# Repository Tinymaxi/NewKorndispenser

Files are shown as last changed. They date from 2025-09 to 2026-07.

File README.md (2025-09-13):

# NewKorndispenser

This is the code for an apparatus that is able to dispense corn out of bags to a given amount.  
It runs on the Raspberry Pi Pico using the official Pico SDK and supports modules such as:

- HX711 load cell amplifier (for weighing)
- Rotary encoder with button (for menu navigation)
- LCD over I²C (for display)
- NeoPixel ring (for feedback/indicators)
- Buzzer/vibrator (for alerts)

The goal is to accurately measure and dispense a configurable quantity of corn.

## License
This project is licensed under the MIT License – see the [LICENSE](LICENSE) file for details.

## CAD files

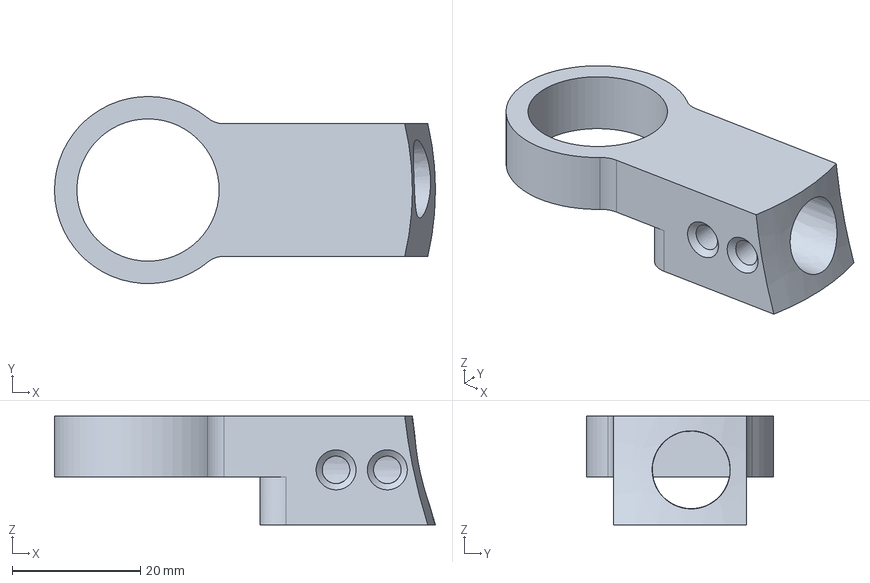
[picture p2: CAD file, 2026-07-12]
Korn Weighing Machine Quote/Insert v25.iges
59.5 x 29.2 x 17.0 mm

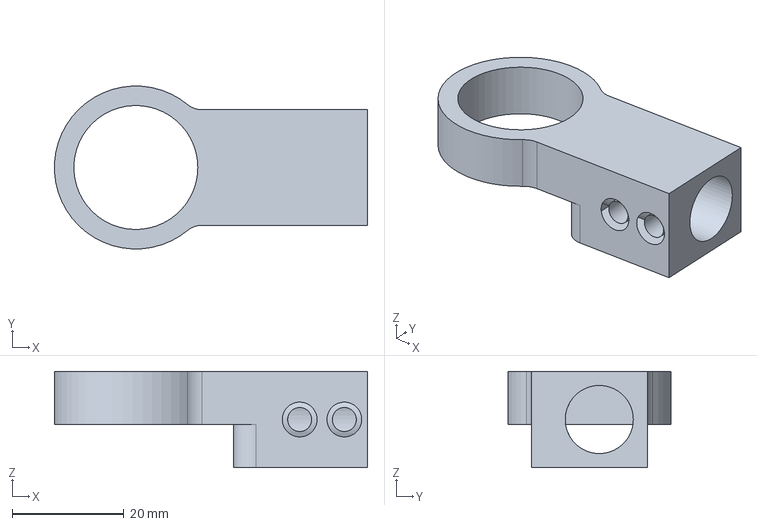
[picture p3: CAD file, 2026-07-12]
resources/Step and iges Files/Insert.step
56.1 x 29.2 x 17.2 mm

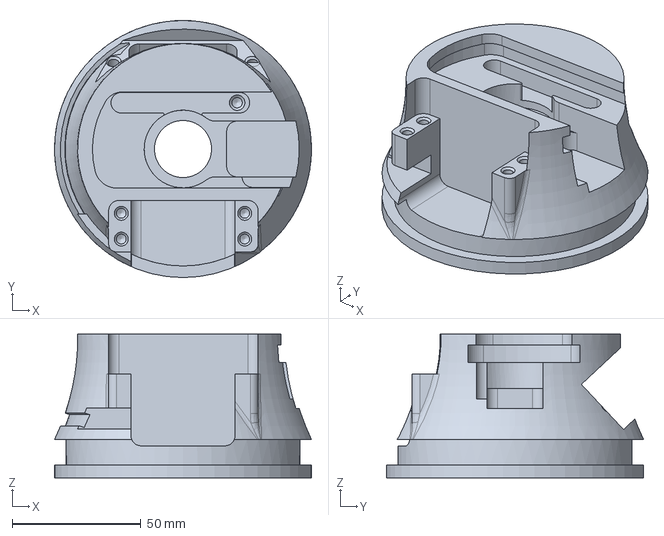
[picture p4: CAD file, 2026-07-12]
Korn Weighing Machine Quote/Funnel v55.step
100.0 x 100.0 x 56.0 mm

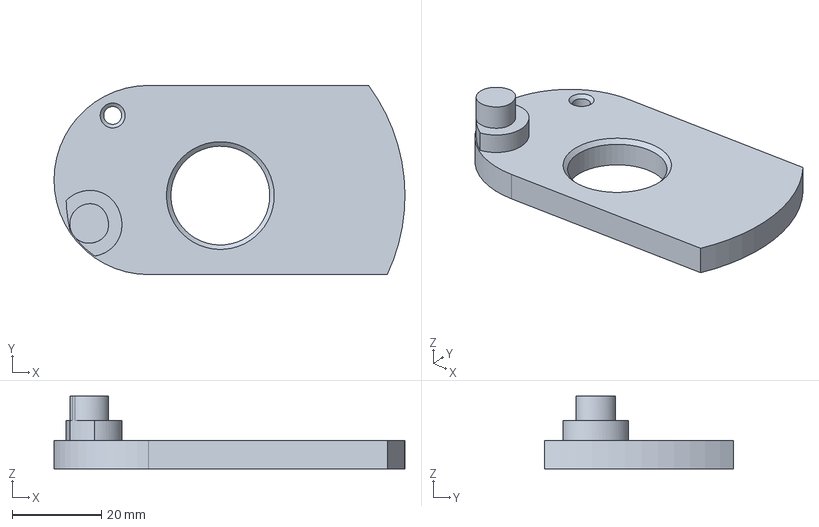
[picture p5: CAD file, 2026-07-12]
Korn Weighing Machine Quote/Slider v8.step
78.9 x 42.5 x 16.3 mm

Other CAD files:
Korn Weighing Machine Quote/Insert v26.step
resources/Step and iges Files/Insert v14.iges
resources/Step and iges Files/Funnel.step
resources/Step and iges Files/Slider v7.iges
resources/Step and iges Files/Slider.step
resources/Step and iges Files/Funnel v27.iges
Korn Weighing Machine Quote/Funnel v55.iges
Korn Weighing Machine Quote/Slider v8.iges

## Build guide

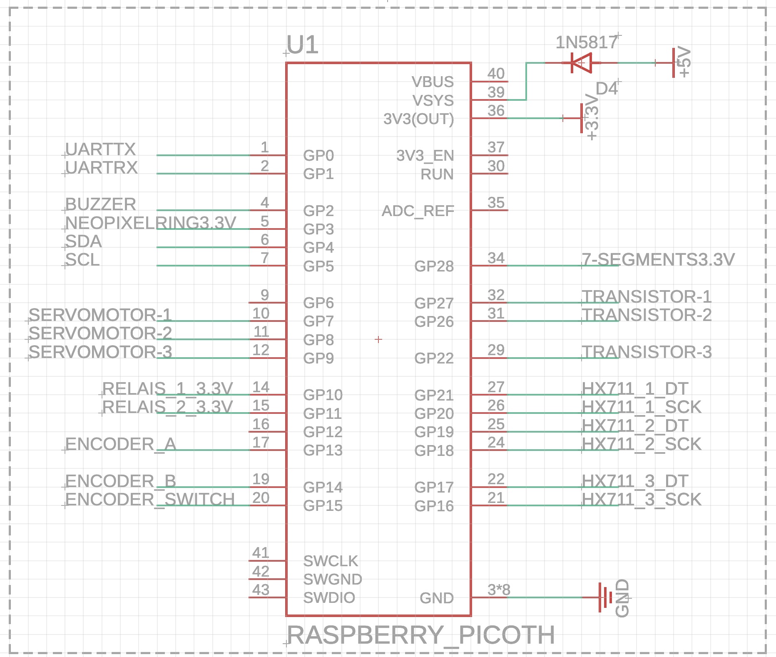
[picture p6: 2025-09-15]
resources/PicoWiring.jpg

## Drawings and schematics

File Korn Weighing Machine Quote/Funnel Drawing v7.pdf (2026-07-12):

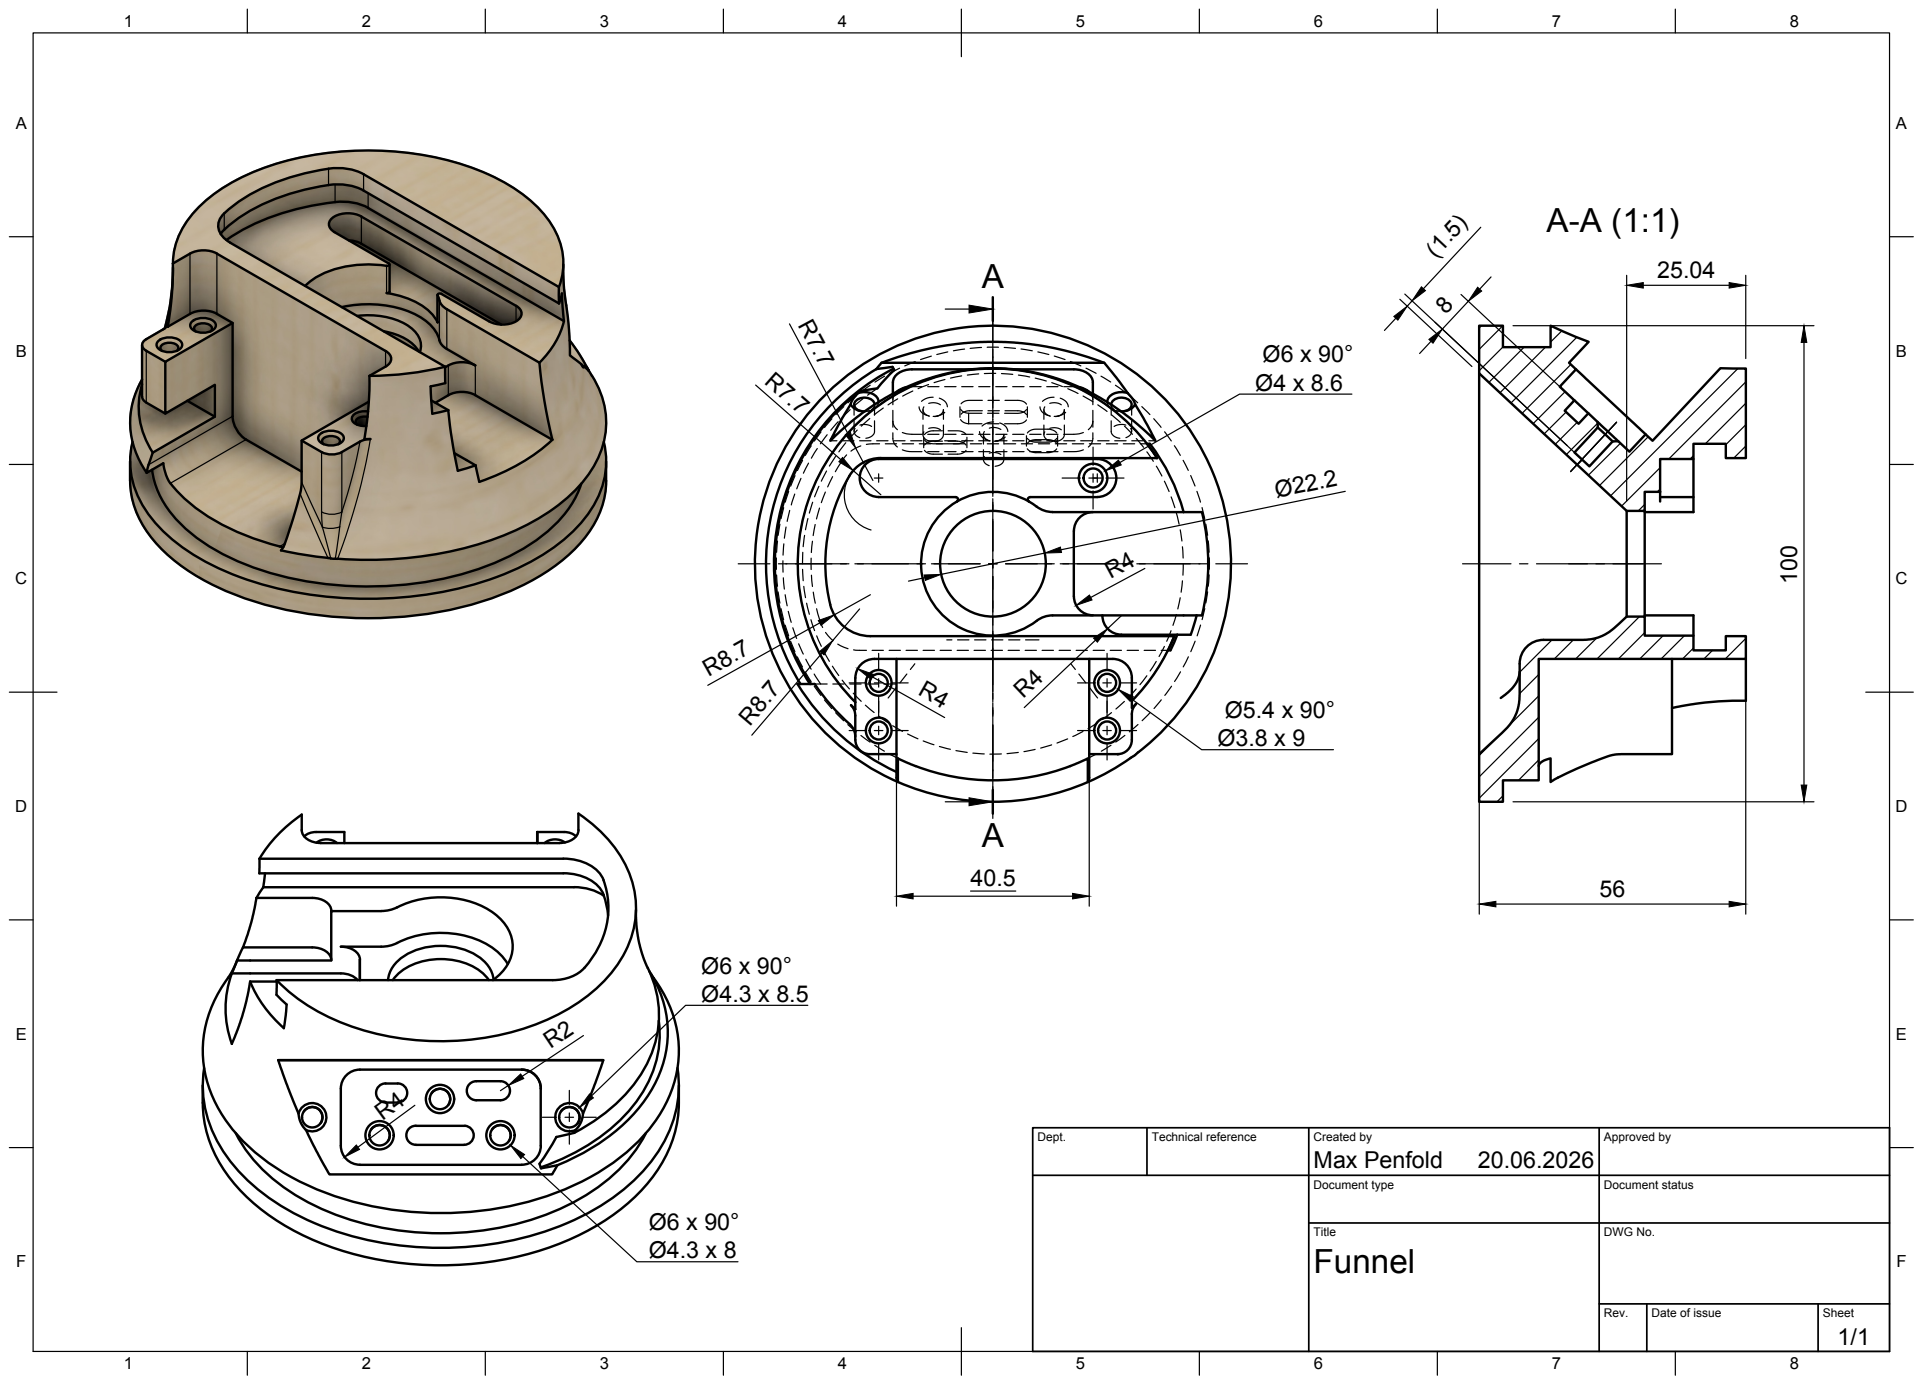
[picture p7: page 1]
Title; DWG No.; Rev.; Date of issue; Sheet

Dept. | Technical reference | Created by Max Penfold 20.06.2026 | Approved by

Document type | Document status

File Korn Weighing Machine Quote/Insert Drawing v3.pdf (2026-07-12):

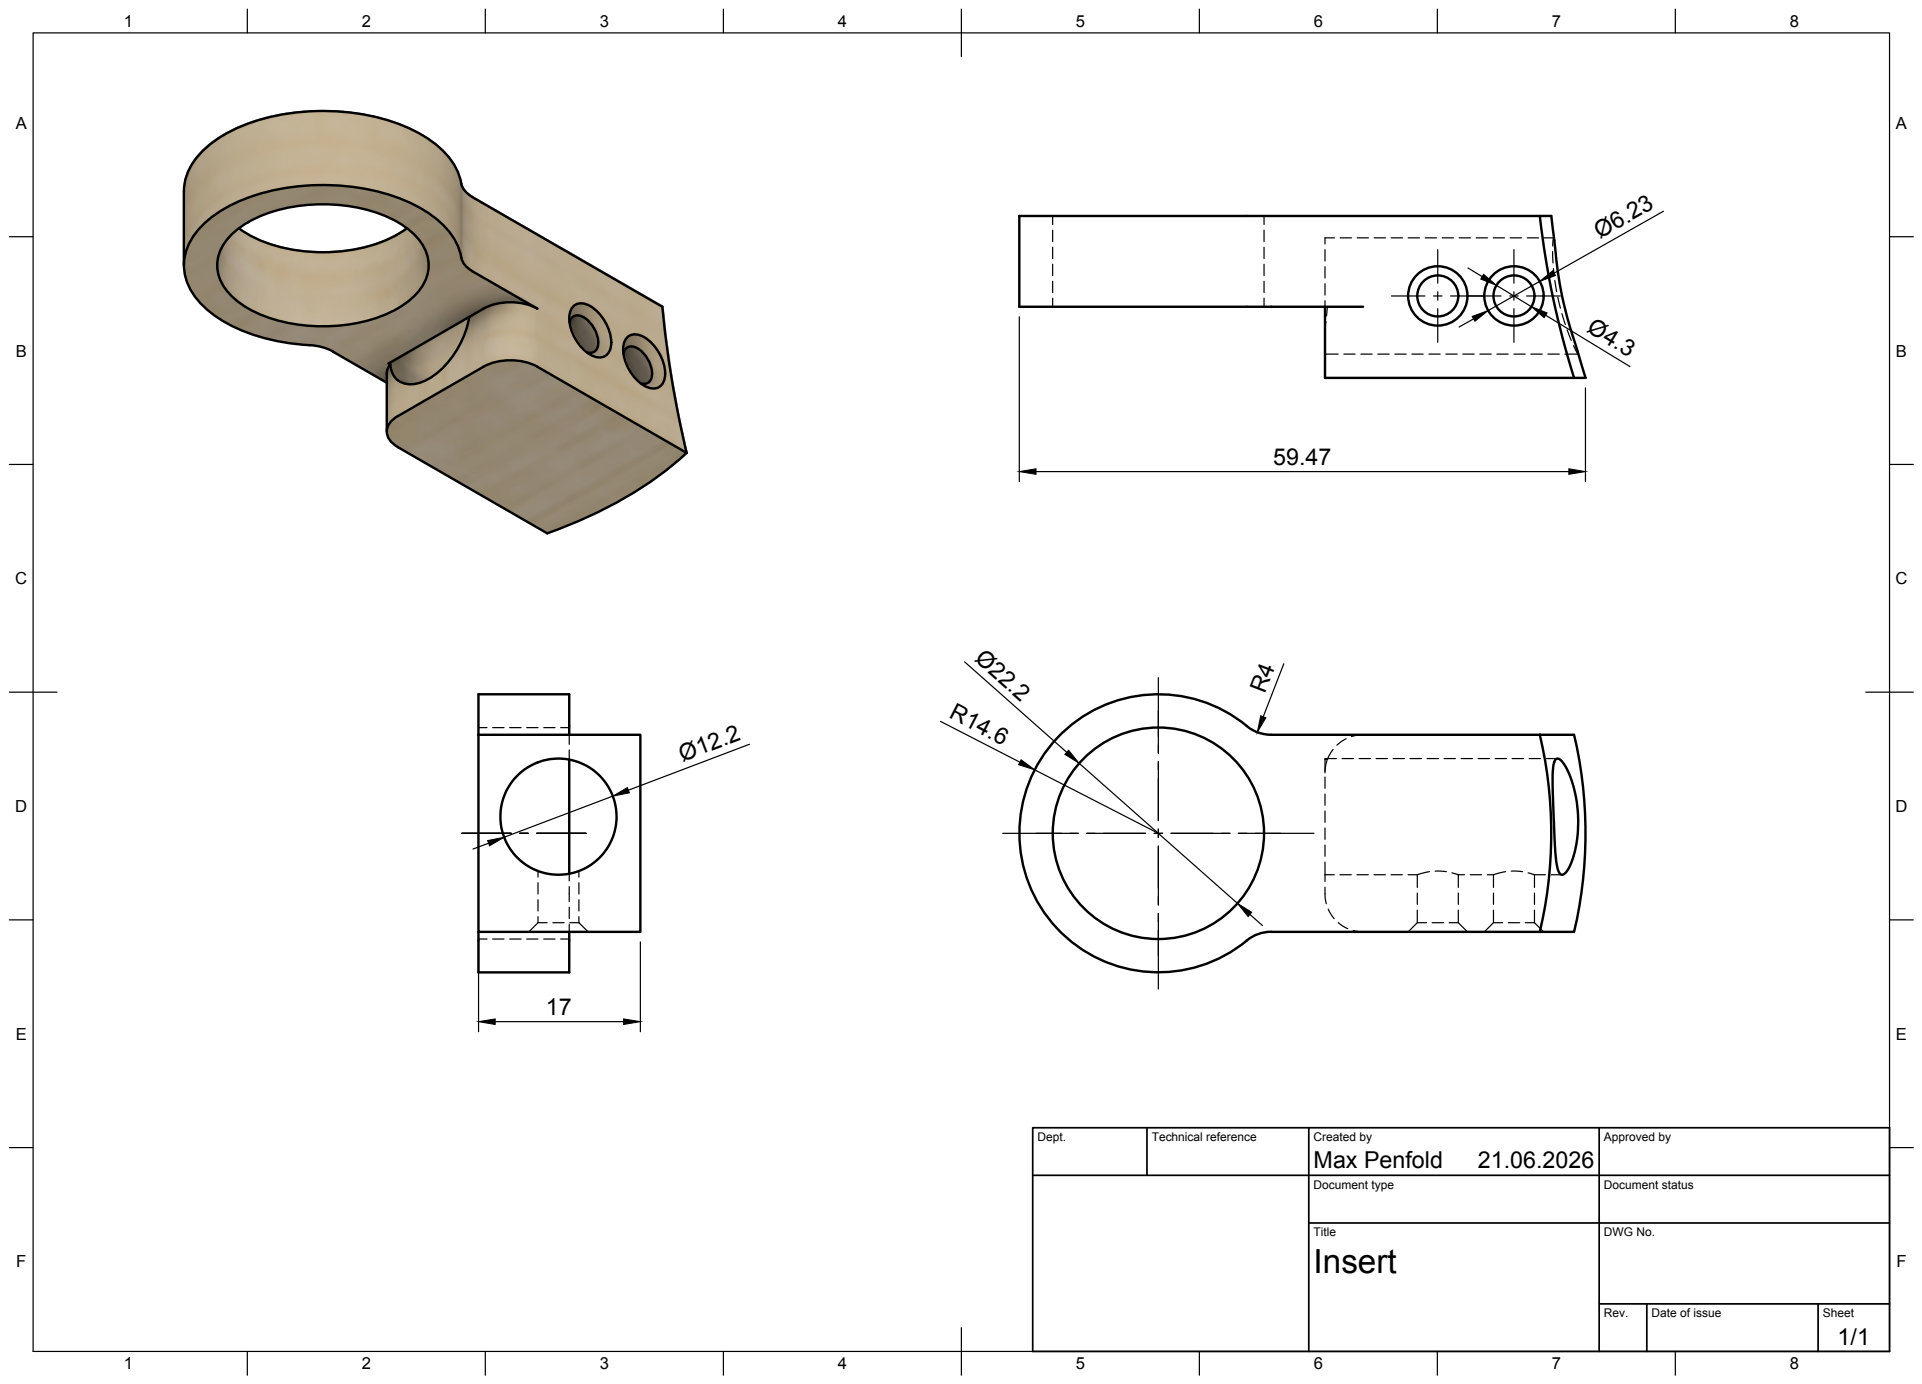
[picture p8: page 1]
Title; DWG No.; Rev.; Date of issue; Sheet

Dept. | Technical reference | Created by Max Penfold 21.06.2026 | Approved by

Document type | Document status

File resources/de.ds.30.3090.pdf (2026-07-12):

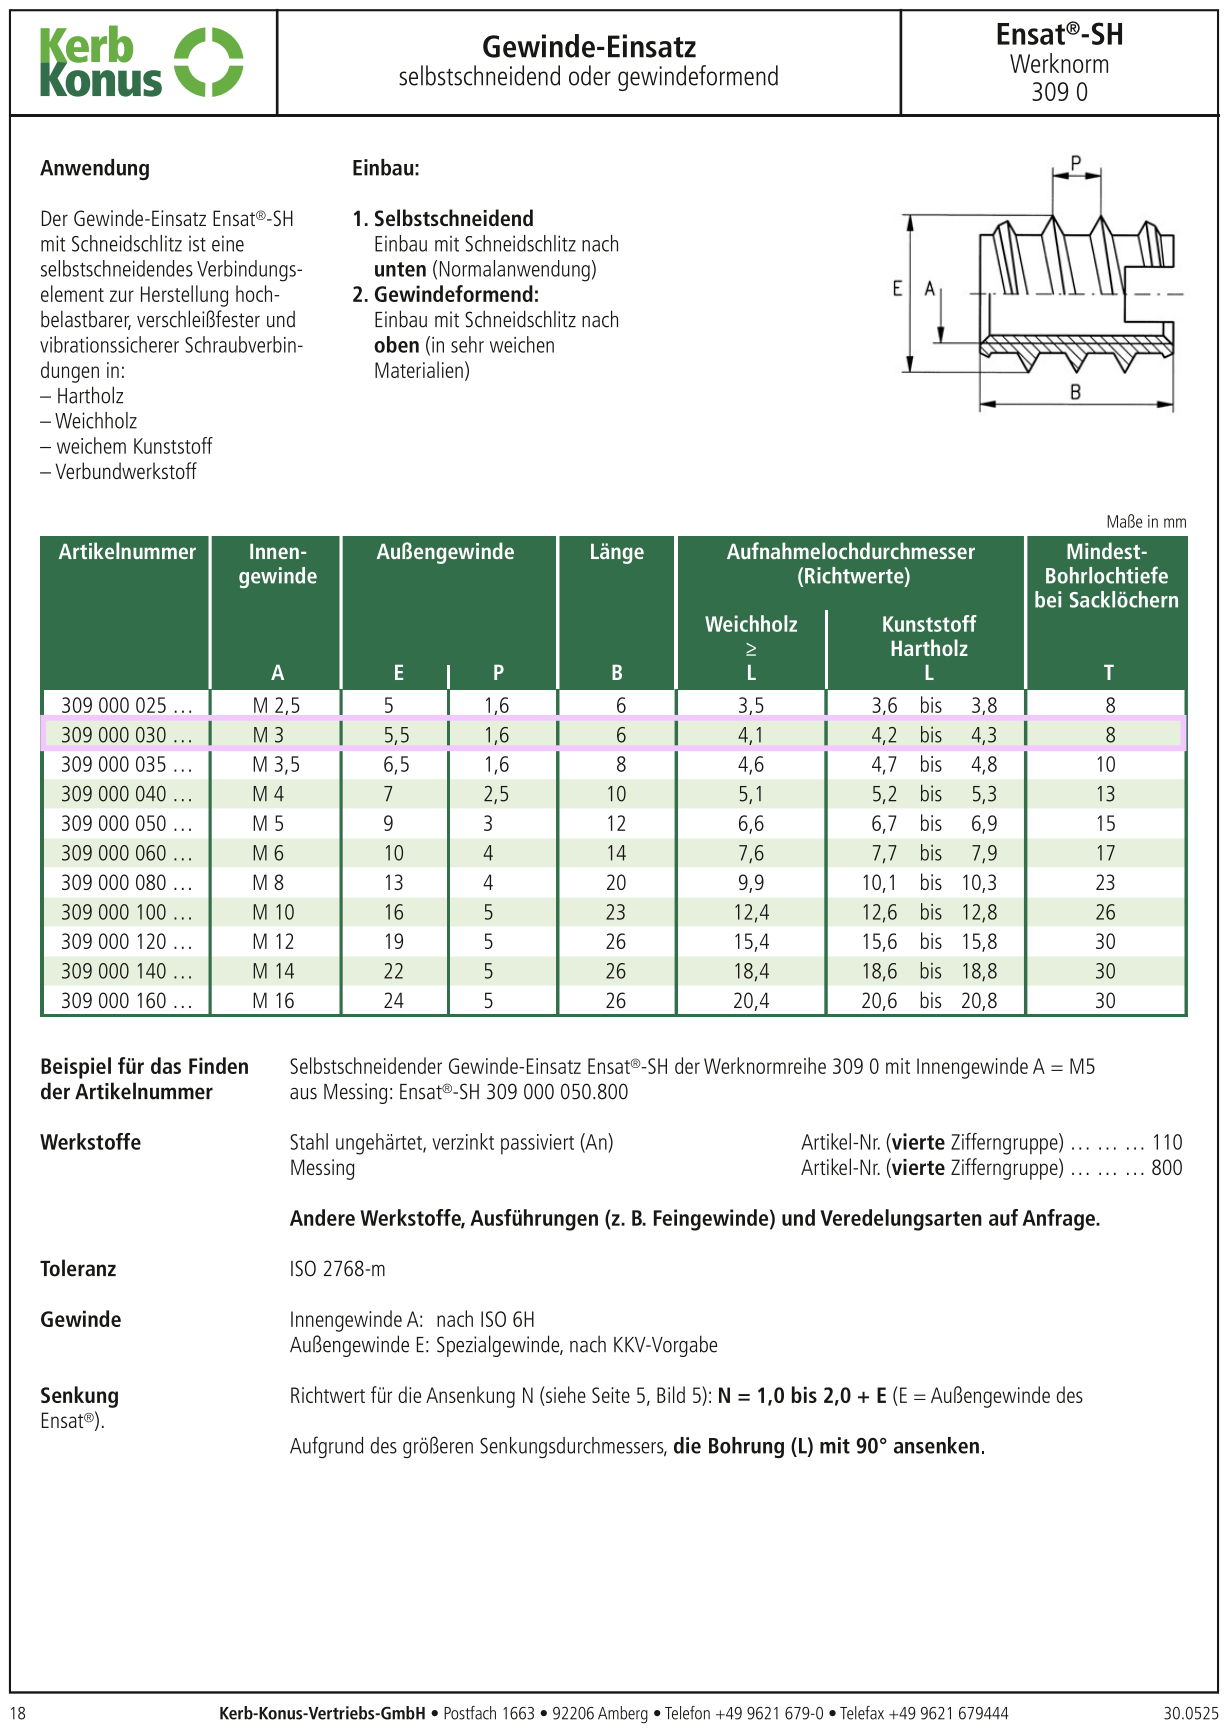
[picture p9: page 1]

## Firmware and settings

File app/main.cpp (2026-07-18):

#include "pico/stdlib.h"
#include "pico/cyw43_arch.h"
#include <cstdio>
#include <cstdlib>

#include "Buzzer.hpp"
#include "Rotary_Button.hpp"
#include "Lcd1602I2C.hpp"
#include "hx711.hpp"
#include "config_store.hpp"
#include "Ws2812.hpp"
#include "SevenSeg.hpp"
#include "Servo.hpp"
#include "Vibrator.hpp"
#include "SharedSlice.hpp"
#include "PID.hpp"
#include "screens.hpp"

#include "wifi_config.h"
#include "dispenser_state.h"
#include "web_server.h"
#include "dhserver.h"
#include "lwip/apps/mdns.h"

constexpr uint BUZZER_PIN = 2;
constexpr uint SEVENSEG_PIN = 28;
constexpr uint SEVENSEG_LEDS = 48;  // 6 digits x 8 segments

Rotary_Button enc;
Buzzer bz(BUZZER_PIN);
Lcd1602I2C lcd(i2c0, 0x27, 20, 4);

// Three load cell scales (from schematic)
hx711 scale1(20, 21);  // HX711_1: GP20=SCK, GP21=DT
hx711 scale2(18, 19);  // HX711_2: GP18=SCK, GP19=DT
hx711 scale3(16, 17);  // HX711_3: GP16=SCK, GP17=DT

// Array for easy access by index
hx711* scales[3] = {&scale1, &scale2, &scale3};

// Dispenser actuators - one per scale
Servo servo1(7);      // Scale 1 servo - GPIO 7
Servo servo2(8);      // Scale 2 servo - GPIO 8
Servo servo3(9);      // Scale 3 servo - GPIO 9
Servo* servos[3] = {&servo1, &servo2, &servo3};

Vibrator vib1(27);    // Scale 1 vibrator - GPIO 27
Vibrator vib2(26);    // Scale 2 vibrator - GPIO 26
Vibrator vib3(22);    // Scale 3 vibrator - GPIO 22
Vibrator* vibrators[3] = {&vib1, &vib2, &vib3};

// servo1 (GP7) and vib3 (GP22) both live on PWM slice 3, which can only hold one
// frequency. This coordinator runs the slice at the servo's 333 Hz whenever servo1
// is active and hands it back to the vibrator's 20 kHz otherwise (see main()).
SharedSlice slice3_pwm;

// Pointers - initialized in main() to avoid PIO conflict with encoder
Ws2812* sevenSegStrip = nullptr;
SevenSeg* sevenSeg = nullptr;

ScaleConfig sc;

// Shared state for web interface
DispenserState g_state;

// True once cyw43_arch_init() has succeeded - lwIP callbacks may then run in the
// background IRQ context, and shared state must be guarded with the lwIP lock.
static bool net_stack_up = false;
static inline void net_lock()   { if (net_stack_up) cyw43_arch_lwip_begin(); }
static inline void net_unlock() { if (net_stack_up) cyw43_arch_lwip_end(); }

// PID tuning parameters (mutable for web-based tuning)
static double Kp = 1.5, Ki = 0.08, Kd = 0.8;
static PID* dispense_pid = nullptr;
static bool pid_save_pending = false;  // Deferred flash save (never write mid-dispense)

static void save_pid_gains() {
    PidConfig pc;
    pc.kp = (float)Kp;
    pc.ki = (float)Ki;
    pc.kd = (float)Kd;
    save_pid_config(pc);  // stalls IRQs ~100 ms - only call while not dispensing
}

// Scale content names ("Wheat", "Spelt", ...) - mirrored in g_state.names for
// the web UI and persisted to flash. Deferred like the PID save: flash writes
// stall IRQs ~100 ms and must never land mid-dispense.
static bool name_save_pending = false;

static void save_scale_names() {
    NameConfig nc;
    for (int i = 0; i < 3; i++) {
        std::snprintf(nc.names[i], SCALE_NAME_LEN, "%s", g_state.names[i]);
    }
    save_name_config(nc);
}

// Per-servo zero (flow-start) angles - mirrored in g_state.servo_zero and
// persisted to flash. Same deferred-save rule as the PID gains and names.
static bool servo_save_pending = false;

static void save_servo_zeros() {
    ServoConfig svc;
    for (int i = 0; i < 3; i++) {
        svc.open_deg[i] = g_state.servo_zero[i];
    }
    save_servo_config(svc);
}

// --- Access-point fallback ---------------------------------------------------
// When the router is unreachable, the Pico broadcasts its own network so a phone
// can join it directly and use the web app at http://192.168.4.1.
static dhcp_entry_t dhcp_entries[] = {
    { {0}, {192, 168, 4, 16}, {255, 255, 255, 0}, 24 * 3600 },
    { {0}, {192, 168, 4, 17}, {255, 255, 255, 0}, 24 * 3600 },
    { {0}, {192, 168, 4, 18}, {255, 255, 255, 0}, 24 * 3600 },
    { {0}, {192, 168, 4, 19}, {255, 255, 255, 0}, 24 * 3600 },
};

static dhcp_config_t dhcp_cfg = {
    {192, 168, 4, 1},                // server address
    67,                              // port
    {192, 168, 4, 1},                // dns (points at us; we run no DNS - harmless)
    "korn",                          // domain suffix
    sizeof(dhcp_entries) / sizeof(dhcp_entries[0]),
    dhcp_entries
};

// Announce this device as http://korn.local via mDNS/Bonjour so a printed QR
// code works regardless of the DHCP-assigned IP. netif_default is the active
// interface in both STA and AP mode. Call after the IP is up.
static void start_mdns() {
    cyw43_arch_lwip_begin();
    mdns_resp_init();
    mdns_resp_add_netif(netif_default, "korn");
    mdns_resp_add_service(netif_default, "korn", "_http", DNSSD_PROTO_TCP, 80, NULL, NULL);
    mdns_resp_announce(netif_default);
    cyw43_arch_lwip_end();
    printf("[mdns] korn.local up\n");
}

static bool start_ap_mode() {
    cyw43_arch_disable_sta_mode();
    // The AP netif is auto-configured to 192.168.4.1/24 by the cyw43 driver
    cyw43_arch_enable_ap_mode(WIFI_AP_SSID, WIFI_AP_PASSWORD, CYW43_AUTH_WPA2_AES_PSK);

    cyw43_arch_lwip_begin();
    err_t e = dhserv_init(&dhcp_cfg);
    cyw43_arch_lwip_end();
    if (e != ERR_OK) {
        printf("[wifi] AP dhcp server failed: %d\n", (int)e);
        return false;
    }
    printf("[wifi] AP mode: %s at 192.168.4.1\n", WIFI_AP_SSID);
    return true;
}

int main()
{
    stdio_init_all();

    // Load persisted PID gains (if ever saved) before the controller is created
    {
        PidConfig pc;
        if (load_pid_config(pc)) {
            Kp = pc.kp;
            Ki = pc.ki;
            Kd = pc.kd;
        }
    }

    // Load persisted scale content names
    {
        NameConfig nc;
        if (load_name_config(nc)) {
            for (int i = 0; i < 3; i++) {
                std::snprintf(g_state.names[i], sizeof(g_state.names[i]), "%s", nc.names[i]);
            }
        }
    }

    // Load persisted servo zero angles (before the startup close below, which
    // parks each servo relative to its zero)
    {
        ServoConfig svc;
        if (load_servo_config(svc)) {
            for (int i = 0; i < 3; i++) {
                g_state.servo_zero[i] = svc.open_deg[i];
            }
        }
    }

    // Link servo1 + vib3 on shared PWM slice 3 before any servo/vibrator output, so
    // the slice frequency is arbitrated from the very first startup close below.
    servo1.attachShared(&slice3_pwm);
    vib3.attachShared(&slice3_pwm);

    // Close all servos at startup, then release (no holding torque)
    for (int i = 0; i < 3; i++) {
        servos[i]->writeDegrees(servo_close(g_state, i));
    }
    sleep_ms(500);  // Give servos time to reach position
    for (int i = 0; i < 3; i++) {
        servos[i]->off();  // Release - no holding torque
    }

    // Give USB serial a moment to connect (non-blocking)
    sleep_ms(1000);
    printf("Ready.\r\r\n");

    lcd.init(PICO_DEFAULT_I2C_SDA_PIN, PICO_DEFAULT_I2C_SCL_PIN, 100000);

    // --- Network mode chooser --------------------------------------------
    // Pick Home WiFi (STA, still falls back to the hotspot if it fails) or
    // Hotspot (AP) with the encoder. Auto-continues with the remembered
    // choice after 5 s, so unattended power cycles never wait on a person.
    uint8_t net_mode = 0;  // 0 = Home WiFi, 1 = Hotspot
    {
        NetConfig ncfg;
        if (load_net_config(ncfg)) net_mode = ncfg.mode;

        lcd.clear();
        lcd.setCursor(0, 0);
        lcd.print("Network?");

        int  sel = net_mode;
        int  last_sel = -1, last_secs = -1;
        int  last_pos = enc.getPosition();
        absolute_time_t deadline = make_timeout_time_ms(5000);

        // Glitch protection: right after boot the button line can show a
        // spurious edge and the encoder's stable-position filter settles with
        // one jump - either instantly "confirmed" the menu. So: ignore
        // position changes during a warm-up, arm the button only after it has
        // read released continuously for 150 ms, and require two consecutive
        // pressed reads (~60 ms) to confirm.
        absolute_time_t warmup = make_timeout_time_ms(300);
        absolute_time_t released_since = get_absolute_time();
        bool armed = false;
        int  press_reads = 0;

        while (!time_reached(deadline)) {
            int pos = enc.getPosition();
            if (pos != last_pos) {
                if (time_reached(warmup)) {
                    sel = (pos > last_pos) ? 1 : 0;  // two entries: turn down/up
                    deadline = make_timeout_time_ms(5000);  // interaction resets timer
                }
                last_pos = pos;
            }

            if (enc.isPressed()) {
                if (armed && ++press_reads >= 2) {
                    printf("[net] chooser: confirmed by press\n");
                    break;
                }
                released_since = get_absolute_time();  // not armed: keep waiting
            } else {
                press_reads = 0;
                if (!armed &&
                    absolute_time_diff_us(released_since, get_absolute_time()) >= 150000) {
                    armed = true;
                }
            }

            if (sel != last_sel) {
                lcd.setCursor(1, 0);
                lcd.print(sel == 0 ? "> Home WiFi    " : "  Home WiFi    ");
                lcd.setCursor(2, 0);
                lcd.print(sel == 1 ? "> Hotspot      " : "  Hotspot      ");
                last_sel = sel;
            }
            int secs = (int)((absolute_time_diff_us(get_absolute_time(), deadline)
                              + 999999) / 1000000);
            if (secs != last_secs) {
                char cdl[21];
                std::snprintf(cdl, sizeof(cdl), "Auto in %ds  Press=OK", secs);
                lcd.setCursor(3, 0);
                lcd.print(cdl);
                last_secs = secs;
            }
            sleep_ms(30);
        }

        printf("[net] chooser result: %s\n", sel == 1 ? "Hotspot" : "Home WiFi");
        if ((uint8_t)sel != net_mode) {
            net_mode = (uint8_t)sel;
            ncfg.mode = net_mode;
            save_net_config(ncfg);  // remembered as next boot's default
        }
    }

    // --- WiFi initialization ---
    if (cyw43_arch_init()) {
        printf("[wifi] init failed\n");
        lcd.clear();
        lcd.setCursor(0, 0);
        lcd.print("WiFi init failed!");
        sleep_ms(2000);
    } else {
        net_stack_up = true;

        // Hotspot chosen at the boot menu skips the STA attempts entirely
        bool force_ap = (net_mode == 1);

        int wifi_err = -1;
        if (!force_ap) {
            cyw43_arch_enable_sta_mode();
            lcd.clear();
            lcd.setCursor(0, 0);
            lcd.print("Connecting WiFi...");
            lcd.setCursor(1, 0);
            lcd.print(WIFI_SSID);
            printf("[wifi] connecting to %s...\n", WIFI_SSID);

            for (int attempt = 1; attempt <= 3 && wifi_err != 0; attempt++) {
                printf("[wifi] attempt %d/3...\n", attempt);
                lcd.setCursor(2, 0);
                char att_line[21];
                std::snprintf(att_line, sizeof(att_line), "Attempt %d/3...      ", attempt);
                lcd.print(att_line);

                wifi_err = cyw43_arch_wifi_connect_timeout_ms(
                    WIFI_SSID, WIFI_PASSWORD, CYW43_AUTH_WPA2_AES_PSK, 20000);

                if (wifi_err) {
                    printf("[wifi] attempt %d failed: %d\n", attempt, wifi_err);
                }
            }
        }

        if (wifi_err == 0) {
            const ip4_addr_t* ip = netif_ip4_addr(netif_default);
            char ip_str[20];
            snprintf(ip_str, sizeof(ip_str), "%s", ip4addr_ntoa(ip));
            printf("[wifi] connected: %s\n", ip_str);

            lcd.setCursor(2, 0);
            char ip_line[21];
            std::snprintf(ip_line, sizeof(ip_line), "IP: %s", ip_str);
            lcd.print(ip_line);
            lcd.setCursor(3, 0);
            lcd.print("http://korn.local");

            // Start web server + mDNS (korn.local)
            web_server_init(&g_state, WEB_SERVER_PORT);
            start_mdns();
            sleep_ms(2000);
        } else {
            // STA failed (or AP forced) - broadcast our own network instead
            if (!force_ap) printf("[wifi] all attempts failed: %d\n", wifi_err);
            lcd.clear();
            lcd.setCursor(0, 0);
            lcd.print(force_ap ? "Hotspot mode" : "WiFi failed - AP up");

            if (start_ap_mode()) {
                g_state.ap_mode = true;
                lcd.setCursor(1, 0);
                lcd.print("AP: " WIFI_AP_SSID);
                lcd.setCursor(2, 0);
                lcd.print("Pass: " WIFI_AP_PASSWORD);
                lcd.setCursor(3, 0);
                lcd.print("http://192.168.4.1");

                web_server_init(&g_state, WEB_SERVER_PORT);
                start_mdns();   // korn.local works in AP mode too
                sleep_ms(4000);
            } else {
                lcd.setCursor(3, 0);
                lcd.print("Continuing offline..");
                sleep_ms(3000);
            }
        }
    }

    bz.playMacStartup(); // Mac-like startup chime

    // Initialize 7-segment display after encoder to avoid PIO conflict.
    // Full brightness for the boot animation; dimmed to ~1/3 after it.
    sevenSegStrip = new Ws2812(SEVENSEG_PIN, SEVENSEG_LEDS);
    sevenSeg = new SevenSeg(*sevenSegStrip, LAYOUT_6DIGITS);

    // --- 7-segment startup animation: random segments sweep left to right ---
    {
        const uint8_t ORANGE_R = 255, ORANGE_G = 80, ORANGE_B = 0;
        const int SWEEP_DELAY_MS = 40;  // Speed of sweep
        const int HOLD_MS = 3300;       // Hold at end before clearing

        // Seed random with time
        srand(to_ms_since_boot(get_absolute_time()));

        // Sweep from left to right, lighting random segments
        for (int digit = 0; digit < 6; digit++) {
            // Generate random segment mask (at least 2 segments lit)
            uint8_t mask = 0;
            int lit_count = 0;
            while (lit_count < 2) {
                mask = rand() % 128;  // 7 bits for 7 segments
                lit_count = 0;
                for (int b = 0; b < 7; b++) {
                    if (mask & (1 << b)) lit_count++;
                }
            }

            sevenSeg->setDigitMask(digit, mask, ORANGE_R, ORANGE_G, ORANGE_B);
            sevenSeg->show();
            sleep_ms(SWEEP_DELAY_MS);
        }

        // Brief hold showing all random segments
        sleep_ms(HOLD_MS);

        // Quick fade out sweep right to left
        for (int digit = 5; digit >= 0; digit--) {
            sevenSeg->setDigitMask(digit, 0, 0, 0, 0);
            sevenSeg->show();
            sleep_ms(SWEEP_DELAY_MS / 2);
        }
    }

    // Normal operation runs dimmed (~1/3) - full white was blinding
    sevenSegStrip->setBrightness(85);

    bool isConfigured = false;

    if (load_scale_config(sc))
    {
        // Apply config to all 3 scales
        apply_scale_config(scale1, sc.entries[0]);
        apply_scale_config(scale2, sc.entries[1]);
        apply_scale_config(scale3, sc.entries[2]);

        // Check if at least one scale is configured
        int configured_count = 0;
        for (int i = 0; i < 3; i++) {
            if (scales[i]->get_offset() != 0 || scales[i]->get_scale() != 1.0f) {
                configured_count++;
            }
        }

        lcd.clear();
        if (configured_count == 0)
        {
            lcd.setCursor(0, 0);
            lcd.print("     No valid");
            lcd.setCursor(1, 0);
            lcd.print("  config in flash!   ");
            lcd.setCursor(2, 0);
            lcd.print("Please calibrate");
            sleep_ms(2500);
        }
        else
        {
            isConfigured = true;
            lcd.setCursor(0, 0);
            lcd.print("   Loaded config   ");
            char line[21];
            std::snprintf(line, sizeof(line), "%d of 3 scales ready", configured_count);
            lcd.setCursor(1, 0);
            lcd.print(line);
            sleep_ms(2500);
        }
    }
    else
    {
        lcd.clear();
        lcd.setCursor(0, 0);
        lcd.print("     No valid");
        lcd.setCursor(1, 0);
        lcd.print("  config in flash   ");
        sleep_ms(2500);
    }

    // UI context shared by the screen classes (app/screens.cpp) and the web
    // command dispatcher below
    UiContext ctx{
        lcd, enc, bz, scales, servos, vibrators, sevenSeg, sc, g_state,
        Kp, Ki, Kd, dispense_pid, &net_lock, &net_unlock
    };
    ctx.names = g_state.names;

    ScreenManager mgr;
    mgr.init(ctx, isConfigured ? ScreenId::Menu : ScreenId::SelectScale);

    // Timestamp for periodic background weight reads
    absolute_time_t last_bg_weight_time = get_absolute_time();
    int bg_weight_cycle = 0;  // cycles through non-selected scales

    while (true)
    {
        // --- Web state sync: update g_state from local variables ---
        // Scale reads happen OUTSIDE the lwIP lock (they bit-bang the HX711);
        // only the g_state assignments are guarded so /api/status snapshots
        // taken in the lwIP IRQ context can't tear across fields.
        bool have_weights = false;
        float w_sel = 0.0f, w_other = 0.0f;
        float gr_sel = 0.0f, gr_other = 0.0f;
        int other = (ctx.selected_scale + 1 + bg_weight_cycle) % 3;
        if (absolute_time_diff_us(last_bg_weight_time, get_absolute_time()) > 250000) {
            w_sel = scales[ctx.selected_scale]->read_weight();
            gr_sel = scales[ctx.selected_scale]->last_gross();   // same raw sample
            if (other != ctx.selected_scale) {
                w_other = scales[other]->read_weight();
                gr_other = scales[other]->last_gross();
            }
            have_weights = true;
            bg_weight_cycle = (bg_weight_cycle + 1) % 2;
            last_bg_weight_time = get_absolute_time();
        }

        net_lock();
        g_state.selected_scale = ctx.selected_scale;
        g_state.target_grams = ctx.target_grams;
        if (have_weights) {
            g_state.weights[ctx.selected_scale] = w_sel;
            g_state.gross[ctx.selected_scale] = gr_sel;
            if (other != ctx.selected_scale) {
                g_state.weights[other] = w_other;
                g_state.gross[other] = gr_other;
            }
        }
        g_state.pid_kp = (float)Kp;
        g_state.pid_ki = (float)Ki;
        g_state.pid_kd = (float)Kd;
        for (int i = 0; i < 3; i++) {
            g_state.scale_calibrated[i] =
                (scales[i]->get_offset() != 0 || scales[i]->get_scale() != 1.0f);
        }
        net_unlock();

        // --- Web command dispatch ---
        // Drain ALL queued commands in order (the queue means nothing gets lost
        // while a blocking tare/calibrate stalls the loop). Pop under the lwIP
        // lock, dispatch from the copy.
        while (true) {
            WebCmd c;
            net_lock();
            bool have = (g_state.cmd_tail != g_state.cmd_head);
            if (have) {
                c = g_state.cmd_queue[g_state.cmd_tail];
                g_state.cmd_tail = (uint8_t)((g_state.cmd_tail + 1) % WEBCMD_QUEUE_LEN);
            }
            net_unlock();
            if (!have) break;

            ctx.web_active = true;  // Web is in control, disable hardware input

            switch (c.cmd) {
            case WebCommand::Tare:
                // tare blocks ~1.6 s - never stall the PID with the gate open
                if (g_state.dispensing) break;
                scales[ctx.selected_scale]->tare();
                bz.playMarioCoin();
                // Publish the tared reading immediately so the next status poll
                // shows ~0 instead of the stale pre-tare weight
                {
                    float wnew = scales[ctx.selected_scale]->read_weight();
                    net_lock();
                    g_state.weights[ctx.selected_scale] = wnew;
                    g_state.gross[ctx.selected_scale] = scales[ctx.selected_scale]->last_gross();
                    net_unlock();
                }
                break;

            case WebCommand::SetTarget:
                ctx.target_grams = c.i0;
                if (ctx.target_grams < 1) ctx.target_grams = 1;
                if (ctx.target_grams > 9999) ctx.target_grams = 9999;
                break;

            case WebCommand::SelectScale:
                if (c.i0 >= 0 && c.i0 <= 2) {
                    ctx.selected_scale = c.i0;
                }
                break;

            case WebCommand::StartDispense:
                // Jump to the dispense screen and flag it to auto-start
                if (!g_state.dispensing) {
                    ctx.web_start_dispense = true;
                    g_state.dispense_done = false;
                    mgr.goTo(ctx, ScreenId::Dispense);
                }
                break;

            case WebCommand::StopDispense:
                // Route through the Dispense screen's Running state so the state
                // machine, telemetry and web state all stop consistently. (Closing
                // the servo here alone is not enough - Running would re-open it.)
                if (g_state.dispensing) {
                    ctx.web_stop_dispense = true;
                }
                break;
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

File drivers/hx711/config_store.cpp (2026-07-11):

#include "config_store.hpp"

#include <cstddef>
#include <cstring>

#include "pico/stdlib.h"
#include "hardware/flash.h"
#include "hardware/sync.h" 

#ifndef CFG_SECTOR_SIZE
#define CFG_SECTOR_SIZE   FLASH_SECTOR_SIZE   // 4096
#endif
#ifndef CFG_PAGE_SIZE
#define CFG_PAGE_SIZE     FLASH_PAGE_SIZE     // 256
#endif

static constexpr uint32_t CFG_OFFSET   = (PICO_FLASH_SIZE_BYTES - CFG_SECTOR_SIZE);
static constexpr uint32_t CFG_XIP_ADDR = (XIP_BASE + CFG_OFFSET);

// CRC32 (poly 0xEDB88320)
static uint32_t crc32_calc(const void* data, size_t len) {
    const uint8_t* p = static_cast<const uint8_t*>(data);
    uint32_t c = 0xFFFFFFFFu;
    for (size_t i = 0; i < len; ++i) {
        c ^= p[i];
        for (int b = 0; b < 8; ++b) {
            c = (c >> 1) ^ (0xEDB88320u & (-(int)(c & 1)));
        }
    }
    return ~c;
}

bool load_scale_config(ScaleConfig& cfg) {
    ScaleConfig tmp{};
    std::memcpy(&tmp, reinterpret_cast<const void*>(CFG_XIP_ADDR), sizeof(tmp));

    if (tmp.magic != 0x48583133) return false;

    uint32_t expected = crc32_calc(&tmp, offsetof(ScaleConfig, crc32));
    if (expected != tmp.crc32) return false;

    cfg = tmp;
    return true;
}

bool save_scale_config(const ScaleConfig& cfg_in) {
    alignas(FLASH_PAGE_SIZE) static uint8_t sector_buf[CFG_SECTOR_SIZE];
    std::memset(sector_buf, 0xFF, sizeof(sector_buf));

    ScaleConfig tmp = cfg_in;
    tmp.crc32 = crc32_calc(&tmp, offsetof(ScaleConfig, crc32));
    std::memcpy(sector_buf, &tmp, sizeof(tmp));

    uint32_t irq_state = save_and_disable_interrupts();
    flash_range_erase(CFG_OFFSET, CFG_SECTOR_SIZE);
    flash_range_program(CFG_OFFSET, sector_buf, CFG_SECTOR_SIZE);
    restore_interrupts(irq_state);

    ScaleConfig check{};
    std::memcpy(&check, reinterpret_cast<const void*>(CFG_XIP_ADDR), sizeof(check));
    return (check.magic == tmp.magic) && (check.crc32 == tmp.crc32);
}
// ---- PID gain persistence (second-to-last sector; calibration untouched) ----

static constexpr uint32_t PID_CFG_OFFSET   = (PICO_FLASH_SIZE_BYTES - 2 * CFG_SECTOR_SIZE);
static constexpr uint32_t PID_CFG_XIP_ADDR = (XIP_BASE + PID_CFG_OFFSET);

bool load_pid_config(PidConfig& cfg) {
    PidConfig tmp{};
    std::memcpy(&tmp, reinterpret_cast<const void*>(PID_CFG_XIP_ADDR), sizeof(tmp));

    if (tmp.magic != 0x50494431) return false;

    uint32_t expected = crc32_calc(&tmp, offsetof(PidConfig, crc32));
    if (expected != tmp.crc32) return false;

    // Reject garbage that happens to pass CRC-of-garbage odds: gains must be
    // finite and non-negative (NaN fails all comparisons, so use !(x >= 0)).
    if (!(tmp.kp >= 0.0f) || !(tmp.ki >= 0.0f) || !(tmp.kd >= 0.0f)) return false;
    if (tmp.kp > 1000.0f || tmp.ki > 1000.0f || tmp.kd > 1000.0f) return false;

    cfg = tmp;
    return true;
}

bool save_pid_config(const PidConfig& cfg_in) {
    alignas(FLASH_PAGE_SIZE) static uint8_t sector_buf[CFG_SECTOR_SIZE];
    std::memset(sector_buf, 0xFF, sizeof(sector_buf));

    PidConfig tmp = cfg_in;
    tmp.magic = 0x50494431;
    tmp.crc32 = crc32_calc(&tmp, offsetof(PidConfig, crc32));
    std::memcpy(sector_buf, &tmp, sizeof(tmp));

    uint32_t irq_state = save_and_disable_interrupts();
    flash_range_erase(PID_CFG_OFFSET, CFG_SECTOR_SIZE);
    flash_range_program(PID_CFG_OFFSET, sector_buf, CFG_SECTOR_SIZE);
    restore_interrupts(irq_state);

    PidConfig check{};
    std::memcpy(&check, reinterpret_cast<const void*>(PID_CFG_XIP_ADDR), sizeof(check));
    return (check.magic == tmp.magic) && (check.crc32 == tmp.crc32);
}

// ---- Per-scale content names (third-to-last sector) -------------------------

static constexpr uint32_t NAME_CFG_OFFSET   = (PICO_FLASH_SIZE_BYTES - 3 * CFG_SECTOR_SIZE);
static constexpr uint32_t NAME_CFG_XIP_ADDR = (XIP_BASE + NAME_CFG_OFFSET);

bool load_name_config(NameConfig& cfg) {
    NameConfig tmp{};
    std::memcpy(&tmp, reinterpret_cast<const void*>(NAME_CFG_XIP_ADDR), sizeof(tmp));

    if (tmp.magic != 0x4E414D31) return false;

    uint32_t expected = crc32_calc(&tmp, offsetof(NameConfig, crc32));
    if (expected != tmp.crc32) return false;

    // Enforce termination and printable ASCII (the names travel through JSON,
    // CSV metadata and the HD44780 LCD)
    for (int i = 0; i < 3; i++) {
        tmp.names[i][SCALE_NAME_LEN - 1] = '\0';
        for (char* p = tmp.names[i]; *p; ++p) {
            if (*p < 0x20 || *p > 0x7E) { *p = '\0'; break; }
        }
    }

    cfg = tmp;
    return true;
}
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

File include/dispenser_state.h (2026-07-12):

#ifndef _DISPENSER_STATE_H
#define _DISPENSER_STATE_H

#include <cstdint>

enum class WebCommand : uint8_t {
    None = 0,
    Tare,
    StartDispense,
    StopDispense,
    SetTarget,
    SelectScale,
    TestServo,
    TestVibrator,
    TestStop,
    Calibrate,
    SetPID,
    SetName,
    SetServoZero,
    EStop,
};

// One queued web command with its payload
struct WebCmd {
    WebCommand cmd = WebCommand::None;
    int   i0 = 0;                  // target grams / scale index / cal weight
    float f0 = 0, f1 = 0, f2 = 0;  // servo angle / vib intensity / kp,ki,kd
    char  s0[16] = {0};            // scale content name (SetName)
};

inline constexpr uint8_t WEBCMD_QUEUE_LEN = 8;

struct DispenserState {
    // --- Written by main loop, read by web server ---
    float weights[3]       = {0, 0, 0};   // Tare-relative weight per scale (grams)
    float gross[3]         = {0, 0, 0};   // Absolute (bag) weight per scale (grams),
                                          // vs the calibrated zero - unaffected by tare
    char  names[3][16]     = {{0},{0},{0}};  // Scale contents ("Wheat", "Spelt", ...)
    int   selected_scale   = 0;            // 0-2
    int   target_grams     = 100;
    bool  dispensing       = false;
    bool  dispense_done    = false;
    float dispensed_grams  = 0;            // Amount dispensed so far
    bool  scale_calibrated[3] = {false, false, false};
    float pid_kp = 0;
    float pid_ki = 0;
    float pid_kd = 0;
    float servo_angle    = 0;              // Current servo angle (degrees)
    float vib_intensity  = 0;              // Current vibrator intensity (0-1)
    bool  ap_mode        = false;          // True when serving own AP instead of joining WiFi
    float servo_zero[3]  = {-1, -1, -1};   // Calibrated flow-start angle per servo
                                           // (degrees); < 0 = not calibrated

    // --- Command ring queue: web server (lwIP context) pushes at head, main loop
    // drains from tail under the lwIP lock. A queue (not a single slot) so commands
    // issued while the main loop is busy (e.g. a ~1.5 s blocking tare) are not lost.
    WebCmd cmd_queue[WEBCMD_QUEUE_LEN];
    volatile uint8_t cmd_head = 0;   // next write slot (web server)
    volatile uint8_t cmd_tail = 0;   // next read slot (main loop)
};

// --- Servo working-range helpers -------------------------------------------
// Each dispenser mechanism differs, so the angle where grain starts to flow is
// calibrated per servo (servo_zero[], jogged + saved by the user). Servos
// without a calibration keep the historical fixed values.

inline constexpr float SERVO_CLOSE_BACKOFF_DEG = 15.0f;  // close this far below zero
inline constexpr float SERVO_DEFAULT_MIN_OPEN  = 85.0f;  // uncalibrated PID floor
inline constexpr float SERVO_FULL_OPEN         = 170.0f; // uncalibrated PID ceiling
// Usable travel above the zero: the arm hits a mechanical end stop ~75 deg past
// the flow-start point; +5 deg of lean guarantees "fully open" is reached.
inline constexpr float SERVO_OPEN_SPAN_DEG     = 80.0f;

inline bool servo_zero_set(const DispenserState& s, int i) {
    return s.servo_zero[i] >= 0.0f && s.servo_zero[i] <= 180.0f;
}

// PID lower output limit. Clamped to 175 so min < max always holds (see
// servo_max_open) - PID::SetOutputLimits(min, max) silently ignores min >= max.
inline float servo_min_open(const DispenserState& s, int i) {
    if (!servo_zero_set(s, i)) return SERVO_DEFAULT_MIN_OPEN;
    float z = s.servo_zero[i];
    return z > 175.0f ? 175.0f : z;
}

// PID upper output limit: zero + usable span, capped at the servo's 180 limit.
inline float servo_max_open(const DispenserState& s, int i) {
    if (!servo_zero_set(s, i)) return SERVO_FULL_OPEN;
    float m = s.servo_zero[i] + SERVO_OPEN_SPAN_DEG;
    return m > 180.0f ? 180.0f : m;
}

// Physical closed position: just below the flow-start point instead of a full
// sweep to 0 - faster, gentler closes. Uncalibrated: 0 (historical behavior).
inline float servo_close(const DispenserState& s, int i) {
    if (!servo_zero_set(s, i)) return 0.0f;
    float c = s.servo_zero[i] - SERVO_CLOSE_BACKOFF_DEG;
    return c < 0.0f ? 0.0f : c;
}

#endif // _DISPENSER_STATE_H

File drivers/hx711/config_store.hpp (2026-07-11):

#pragma once
#include <cstdint>

// Stores calibration for up to 3 HX711 instances
struct ScaleEntry {
    int32_t offset_counts = 0;
    float   count_per_g   = 0.0f;  // counts per gram
};

struct ScaleConfig {
    uint32_t magic = 0x48583133;   // "HX13" (HX711, 3 channels)
    ScaleEntry entries[3];         // 3 sets of calibration
    uint32_t crc32 = 0;
};

bool load_scale_config(ScaleConfig& cfg);
bool save_scale_config(const ScaleConfig& cfg);

// PID tuning gains, persisted in the second-to-last flash sector (the scale
// calibration above owns the last sector and is never touched by these).
struct PidConfig {
    uint32_t magic = 0x50494431;   // "PID1"
    float kp = 0.0f;
    float ki = 0.0f;
    float kd = 0.0f;
    uint32_t crc32 = 0;
};

bool load_pid_config(PidConfig& cfg);
bool save_pid_config(const PidConfig& cfg);

// Per-scale content names ("Wheat", "Spelt", ...), persisted in the
// third-to-last flash sector. Changed whenever a bag is swapped.
inline constexpr int SCALE_NAME_LEN = 16;   // 15 chars + NUL

struct NameConfig {
    uint32_t magic = 0x4E414D31;   // "NAM1"
    char names[3][SCALE_NAME_LEN] = {{0}, {0}, {0}};
    uint32_t crc32 = 0;
};

bool load_name_config(NameConfig& cfg);
bool save_name_config(const NameConfig& cfg);

// Per-servo flow-start ("zero") angle in degrees, persisted in the
// fourth-to-last flash sector. open_deg < 0 = servo not calibrated.
struct ServoConfig {
    uint32_t magic = 0x53525631;   // "SRV1"
    float open_deg[3] = {-1.0f, -1.0f, -1.0f};
    uint32_t crc32 = 0;
};

bool load_servo_config(ServoConfig& cfg);
bool save_servo_config(const ServoConfig& cfg);
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

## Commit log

2025-08-08 Initial import – NewKorndispenser layout
2025-08-13 Rotary button with LED working as should.
2025-08-13 Sevensegmenst and button working.
2025-09-14 Hx711 and Buzzer added
    [Buzzer.cpp, config_store.cpp, config_store.hpp]
2025-09-14 Servo Added
2025-09-15 Debugging the button
2025-09-15 fixed button
2026-02-03 Fix rotary encoder for RP2350 and add digit-by-digit calibration UI
    - Fixed PIO quadrature encoder by using PIO1 instead of PIO0 (RP2350 compatibility)
    - Added manual PIO initialization with GPIO input enable for RP2350
    - Implemented digit-by-digit number entry for calibration weight (navigate with encoder, press to edit digit, turn to change 0-9)
    - Added menu arrow indicator for navigation
    - Cleaned up debug output
    [Rotary_Button.cpp, Rotary_Button.hpp, main.cpp]
2026-02-04 Add dispense feature with PID control and vibrator test menu
    - Add Dispense screen with auto-tare, PID-controlled servo, and vibrator
    - Track weight decrease (corn bags hang on load cells)
    - Add Test menu for debugging vibrators (select 1/2/3, adjust 0-100%)
    - Add 80ms time-based debounce for rotary encoder
    - Remove one-time GPIO 10 relay reset code
    [Rotary_Button.cpp, Rotary_Button.hpp, main.cpp]
2026-02-05 Add visual and audio enhancements
    NeoPixel ring animations:
    - Comet trail effect when turning encoder
    - Breathing/pulse effect when idle
    - Ripple animation on button press
    7-segment display:
    - Random segment sweep animation at startup (orange)
    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
2026-02-05 Add calibration exit options and servo release after dispensing
    - Add Back option to Calibrate1 and Calibrate2 screens for easy exit
    - Remove spacing between weigh screen menu options (Tare/Target/Back)
    - Turn off servo PWM after dispensing to release holding torque
2026-02-05 Close servos at startup and release holding torque
    - Servos close to 60° on startup, then PWM turns off to release torque
    - Add Das Boot theme to buzzer (not currently used)
    [Buzzer.cpp, main.cpp]
2026-07-09 Fix servo 1 PWM slice conflict; add PID telemetry, AP fallback, Swiss web UI
    Servo 1 (GP7) was dead: it shares RP2040 PWM slice 3 with vibrator 3
    (GP22), and the vibrator's 20 kHz setup overwrote the servo's 333 Hz.
    New SharedSlice coordinator arbitrates the slice dynamically: 333 Hz
    while servo 1 is active, 20 kHz otherwise (vibrator rescales its duty).
    PID tuning support:
    - 20 Hz telemetry capture of every PID compute during a dispense
    (setpoint, dispensed, weight, servo angle, P/I/D terms, vibrator)
    - GET /api/log.csv streams the run as CSV for offline analysis
    - PID gains persist in a dedicated flash sector (calibration untouched)
    Connectivity:
    - Wi-Fi AP fallback: on STA failure (or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
    [Servo.cpp, SharedSlice.cpp, SharedSlice.hpp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]
2026-07-10 Fix scale staleness/lost commands; add gross bag weight, mDNS, QR sticker
    Scale bugs from first hardware test of the phone app:
    - HX711 reads served ~1 s stale samples (4-deep PIO FIFO, oldest-first);
    read_weight(1) now drains to the newest sample, non-blocking
    - Web commands went through a single overwritable slot and were lost
    during ~1.5 s blocking tares (tare could hit the wrong scale); replaced
    with an 8-entry ring queue drained in order every loop
    - Scale-select flicker was an optimistic-UI vs poll race; the page now
    latches the tapped scale until the firmware confirms it
    - Tare publishes the fresh zeroed weight immediately
    PID loop: the 3-sample blocking read throttled contro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
    [config_store.hpp, dispenser_state.h, main.cpp]
2026-07-10 Refactor LCD screens into Screen classes (state pattern)
    main.cpp's 1200-line screen switch is now 11 Screen classes in
    app/screens.{hpp,cpp} with an enter()/update() lifecycle managed by
    ScreenManager. Per-screen state that lived in function-local statics
    (the recurring source of stale-button/carry-over bugs) is now member
    data initialized in enter().
    Behavior-preserving: per-screen sleep timings, button edge semantics,
    option layouts, 7-segment colors, and the web-control interactions
    (start/stop routing, unlatch, Done-screen web start) are ported
    verbatim. UiContext carries hardware refs and cross-screen UI state;
    the web command dispatcher drives navigation via ScreenManager::goTo.
    mai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
    [main.cpp, screens.cpp]
2026-07-10 Add per-scale content names (grain in each bag)
    Each scale can be labeled with what's in its bag (Wheat, Spelt, ...):
    - Web UI: new Contents section with preset dropdown per scale plus a
    Custom free-text option; scale cards, masthead and dispense history
    show the name; run metadata and the CSV name= field record which
    grain each run dispensed
    - LCD: scale-select rows and Weigh/Dispense headers show the name
    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
2026-07-10 Allow vibrator test to 100%; color the chart series
    The web Test slider capped the vibrator at 60% - it now spans the full
    0-100% range (firmware always accepted 0-1.0).
    Run/live chart series get distinct colors (CVD-validated set, worst
    adjacent deltaE 25 on white): dispensed stays ink, servo blue #2a78d6,
    bag wheat-yellow #eda100, vibrator aqua #1baf7a, P orange / I violet /
    D green (color + distinct dash patterns), target red dashed. Adds a
    legend with white backing, color dots on the toggle buttons, and
    clamps the bag label away from the corner labels.
2026-07-10 Fix mDNS timer-pool panic and dead-scale firmware freeze
    Two failures found via SWD debugging on hardware:
    1. lwIP panicked ~30 s after boot: "pool MEMP_SYS_TIMEOUT is empty".
    The mDNS responder runs probe, announce and multicast-TTL-reset
    timers concurrently; the +1 sys-timeout slot was too few. Now +8.
    (Backtrace: mdns_probe_and_announce -> sys_timeout -> panic.)
    2. A disconnected HX711 froze the whole firmware: the first read of a
    silent sensor blocked forever in pio_sm_get_blocking (frozen LCD,
    dead UI). All reads now use a 150 ms timeout; a dead scale reads
    0 g and is re-probed every 2 s. tare()/calibrate abort cleanly on
    sensor timeout instead of hanging or corru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
2026-07-11 Collapsible sections, digit-wheel inputs, 7-segment flicker fix
    Web app (Mainsail-inspired):
    - Every section header is now a collapsible panel with a chevron;
    open/closed state persists per device (localStorage). Defaults:
    Scales/Dispense/Run Chart open, the rest collapsed.
    - Target and calibration weight use per-digit stepper wheels
    (thousands..ones, big touch targets) instead of a number field -
    any amount like 1337 is four taps. Server sync pauses for 3 s
    after the user touches a wheel.
    7-segment flicker: every UI tick retransmitted all 48 LEDs; a WiFi/
    lwIP interrupt pausing the bit-stream >50us mid-frame made the strip
    latch a partial frame. Ws2812::show() now skips identical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
2026-07-11 Per-servo zero-point calibration with close backoff
    Each dispenser mechanism differs, so the angle where grain starts to
    flow is now calibrated per servo and stored in flash (SRV1, sector -4):
    - The calibrated zero becomes the PID's lower output limit (was a
    hardcoded 85 for all three); limits are set per dispense start.
    - Closing now backs off 15 deg below the zero instead of sweeping to 0
    (faster, gentler; uncalibrated servos keep the old 0-deg close).
    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
2026-07-11 Boot network chooser on LCD; guard tare/calibrate during dispense
    - At boot the LCD asks Home WiFi or Hotspot (encoder to pick, press to
    confirm). Auto-continues with the remembered choice after 5 s, so
    unattended power cycles never wait. Choice persists in flash (NET1,
    sector -5). Replaces the hidden hold-encoder-at-boot trick.
    - Home WiFi still falls back to the hotspot if the router is
    unreachable, exactly as before.
    - Web Tare and Calibrate commands are now ignored while a dispense is
    running: both block the main loop >1.5 s, which froze the PID with
    the gate open.
    [config_store.cpp, config_store.hpp, main.cpp]
2026-07-11 Harden boot network chooser against spurious inputs
    The chooser exited instantly on real hardware - a glitched button read
    right after boot counted as a confirming press. Now: position changes
    are ignored during a 300 ms warm-up (the encoder's stable-position
    filter settles with one jump), the button only arms after reading
    released continuously for 150 ms, and a confirm needs two consecutive
    pressed reads. Exit reason goes to serial for diagnosis.
    [main.cpp]
2026-07-11 Bigger section chevrons (24px); never cache the web page
    The chevrons never actually shrank in the source - the phone was
    serving a cached pre-fix copy of the page, because the HTML response
    carried no Cache-Control header. The page ships inside the firmware,
    so any caching means a stale UI after a flash: now sent with
    Cache-Control: no-store (the CSV endpoint already did this).
    [web_server.cpp]
2026-07-11 Draw section chevrons as CSS shapes; add page version tag
    The Unicode triangle renders tiny on iOS regardless of font-size, so
    the chevron is now drawn with two 3px borders (14px box) - clearly
    visible at any device. A small version tag (v2) in the masthead makes
    a stale cached page instantly recognizable.
2026-07-11 Emergency STOP bar in the web app
    A red STOP bar pins to the bottom of the page whenever something can
    move - during a dispense (from the status poll) or while any test
    control is engaged (servo slider, vibrator slider, servo-zero jog).
    One tap posts /api/estop: a running dispense stops cleanly through the
    state machine (telemetry saved); otherwise all servos close to their
    calibrated positions and release; vibrators always stop. No
    confirmation dialog. Page version -> v3.
    [dispenser_state.h, main.cpp, web_server.cpp]
2026-07-11 Per-run CSV downloads in History; stale-page detector
    - Each finished run's CSV (auto-fetched for the post-run chart) is now
    cached in the browser (newest 8 runs). The History table gets a CSV
    button per run plus Download All Runs (concatenated with meta lines).
    Clear History also clears the cached CSVs.
    - The Download CSV button leaves the Run Chart section (user request -
    downloads live in History now).
    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
2026-07-12 LCD shows "Hotspot 192.168.4.1" instead of bogus RSSI in AP mode
    As an access point there is no router to measure signal against, so
    the Web Control screen printed the -100 dBm placeholder as
    "WiFi: -100 dBm Weak". Show the hotspot address instead.
2026-07-12 Fix 200 ms control loop; ceiling = zero + 80; low-bag warning
    CSV telemetry showed ~193 ms between PID computes (SetSampleTime is
    100 ms). Two compounding causes, both fixed:
    - Lcd1602I2C::pulseEnable slept 3x600 us per nibble (~3.6 ms per
    character) - a heritage of the RPi example code. The I2C byte time
    already satisfies HD44780 timing; delays removed (~10x faster).
    - The Dispense screen repainted two full LCD lines every loop tick.
    Lines now repaint only when their value changes (all three states).
    Servo working range: PID ceiling is now the calibrated zero + 80 deg
    (mechanical end stop sits ~75 deg past zero; +5 deg lean guarantees
    full opening), capped at 180. Uncalibrated servos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
    [Lcd1602I2C.cpp, dispenser_state.h, screens.cpp]
2026-07-12 Dim the 7-segment display to ~1/3 brightness
    Per-strip brightness scaling in Ws2812::setPixel (default 255 = full,
    so the encoder ring is unaffected); the 7-seg strip is set to 85/255.
    All call sites keep passing full-range colors.
2026-07-12 Serve the page for URLs with query strings (fixes white page)
    Routing used exact strcmp, so the stale-page detector's cache-busting
    reload "/?r=<ts>" fell through to a bodyless 404 - a silent white page
    on iPhone Safari, which then autocompletes the poisoned URL on every
    retry. Query strings are now stripped before route matching, and 404s
    carry a visible body. (The mock server served the page for any path,
    which is how this escaped testing.)
    [web_server.cpp]
2026-07-12 Seed PID output at the floor; vibrator at 80 g; boot sweep bright + 3 s
    CSV runs 2-4 (kp 1.5 / ki 0.005 / kd 0.3, true 105 ms cycle) showed
    i_term frozen at 150-175 all run: SetMode(AUTOMATIC)'s bumpless
    transfer latches the PREVIOUS run's final output into the integrator,
    and a tiny Ki never bleeds it off - so the gate rode ~55-80 deg above
    the flow point to the very end. The output is now seeded at the floor
    before enabling, making the end-phase taper to just above flow-start
    (angle = zero + Kp * grams_remaining): slow, precise trickle finish.
    Vibrator assist now starts at 80 g remaining (was 30) - the motor
    needs spin-up time. Boot sweep runs at full brightness and holds 3 s
    longer; norm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
    [main.cpp, screens.cpp]
2026-07-12 Done-confirmation: target must hold for 3 consecutive samples
    The tail readings wobble +-1.5 g (vibrator shakes the scale), so the
    single-sample done check always fired on an upward noise spike - the
    settled weight then measured 2-3 g under target on a reference scale.
    The run now ends only after the reading holds at/above target for 3
    consecutive fresh samples (~300 ms); the floor-riding trickle during
    confirmation biases the settled result onto the target.
    CSV runs 2-4 with floor-seed + recalibrated zero (107 deg): +1.3/+0.1/
    +2.0 g on the machine's scale, trickle ending as intended.
    [screens.cpp]
2026-07-12 Servo slew limit; flow-stall alarm; page v6
    Full-bag CSVs (file 8) showed weight readings swinging +-35 g per
    sample while the servo jumped 108<->180 between samples: the heavy
    bag is a pendulum, the slamming gate pumps it, and the done-check
    fires on an upward swing (266.6 g run). The commanded angle now
    glides at most 10 deg per 100 ms sample - the gate cannot excite the
    oscillation anymore.
    Flow-stall alarm (user request): no +0.3 g progress for 6 s while
    dispensing -> close, triple low beep, "FLOW STALLED / Bag empty?" on
    the LCD, red FLOW STALLED - BAG EMPTY? in the app (new "stalled"
    status field, cleared on next start). Previously an empty bag left
    the gate wide open pouring nothing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
    [dispenser_state.h, screens.cpp, web_server.cpp]
2026-07-12 Remove the flow-stall alarm; page v7
    The 6 s no-progress timeout false-triggered during legitimate slow
    trickle runs (low bag level, gentle end phase) and cut them short. The
    STOP button (app + encoder) already covers a genuinely stuck run, so
    the auto-abort is removed entirely: the "stalled" state field, status
    JSON flag, LCD alarm, and app banner all go with it.
    [dispenser_state.h, screens.cpp, web_server.cpp]
2026-07-12 Add hardware resources (datasheets, funnel CAD, quote); gitignore *.img
    Datasheets (load cell, scale, HX711, Pico 2 W pinout), the funnel
    STEP/IGES/drawings, and the machining quote. The 15 GB disk-image
    backup in resources/ is gitignored (too large for GitHub).
    [Funnel v27.iges, Funnel v55.iges, Funnel v55.step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]
2026-07-18 Lock the web page horizontally on touch devices; page v8
    The whole UI could be dragged sideways on the iPhone, fighting the
    slider controls. Layout audit showed nothing overflows - it is iOS
    gesture behavior: focus auto-zoom (text inputs) leaves the page zoomed
    and pannable, plus pinch-zoom and elastic overscroll. Fixes:
    - viewport meta gains maximum-scale=1 (stops focus auto-zoom)
    - html/body: touch-action:pan-y (vertical panning only),
    overscroll-behavior-x:none, overflow-x:hidden
    - input[type=range]: touch-action:none - a slider drag belongs to the
    slider, never scrolls or pans the page
2026-07-18 7-segment shows weights with two decimal places
    New SevenSeg::printFixed2: right-aligned IIII.DD using the per-digit
    decimal-point LED (6 digits -> up to 9999.99 g). Weight displays switch
    over: Weigh screen, Dispense running/done, Web Control screen. Targets
    and servo angles stay integer.
2026-07-18 LCD: zeroing feedback + menu navigation repair
    Zeroing: tare blocks ~1.6 s and the LCD froze silently. Every LCD tare
    site now shows "Zeroing..." during and "Zeroed!" + beep after (Weigh,
    Calibrate step 1, Dispense Retry).
    Menus: Menu/SelectScale/TestMenu used a LEVEL button check, so a press
    still held from the previous screen cascaded through - Menu re-fired
    straight back into a flow ("stuck on Dispense, can't Back") and
    SelectScale auto-picked a scale before the knob could be turned ("can't
    choose which scale to calibrate"). All three now use the rising-edge
    pattern every other screen uses, plus delta-driven selection that
    starts at the top and clamps at the ends (was absolute encoder
    po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
    [screens.cpp]
2026-07-18 Run chart no longer disappears on touch; page v9
    Touching the page nudges a scroll, iOS slides the Safari toolbar, that
    fires a resize event, the handler re-inits the canvas (which wipes its
    pixels) - and the repaint condition used prevDisp, which stays TRUE
    after a completed run, so the run chart was never redrawn: blank until
    the next dispense. Fixes:
    - resize handler ignores height-only resizes (the toolbar case) - the
    canvas is not touched at all
    - central repaintChart() with the correct condition (R && not currently
    dispensing) used by resize, chart-section reopen, and the P/I/D
    toggles (all three shared the stale-prevDisp bug)
    Verified in mock: chart survives toolbar resize; rep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
